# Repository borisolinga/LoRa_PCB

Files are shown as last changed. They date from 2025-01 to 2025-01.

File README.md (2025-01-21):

# LoRa-Sender PCB

Die Leiterplatte (PCB) des LoRa-Senders deckt alle für dieses Projekt erforderlichen Funktionen ab. Das Design des Schaltplans und der Platinenlayouts wurde mit der EDA-Software (Electronic Design Automation) **Autodesk EAGLE** entwickelt.

## Eigenschaften der Leiterplatte

Die Leiterplatte bietet folgende Hauptfunktionen:

- **LoRa-Datenübertragung:** Das Board ermöglicht eine zuverlässige Kommunikation über LoRa.
- **Status-LED:** Eine LED zeigt durch Blinken an, wenn ein Paket erfolgreich gesendet wurde.
- **Serielle Schnittstelle:** Eine UART/USB-Schnittstelle ermöglicht die Kommunikation mit einem Computer.
- **Mikrocontroller:**  
  - **ATmega328P**, der aufgrund seiner Kompatibilität mit Arduino-Entwicklungsboards ausgewählt wurde.  
 
- **Stromverbrauchsmessung:**  
  - Zwei Jumper sind zur Stromverbrauchsanalyse vorgesehen:  
    1. Für das LoRa-Modul.  
    2. Für das Gesamtsystem.
  - Ein zusätzlicher Jumper ermöglicht die Nutzung einer externen Stromversorgung.

## Projektinhalt

- **Schaltplan:** Enthält das vollständige PCB-Design in Autodesk EAGLE.
- **Stückliste (BOM):** Eine vollständige Liste der verwendeten Komponenten.

## Nutzung

1. **Repository klonen:**

   ```bash
   git clone https://github.com/borisolinga/LoRa_Transmitter_PCB.git
   cd LoRa_Transmitter_PCB

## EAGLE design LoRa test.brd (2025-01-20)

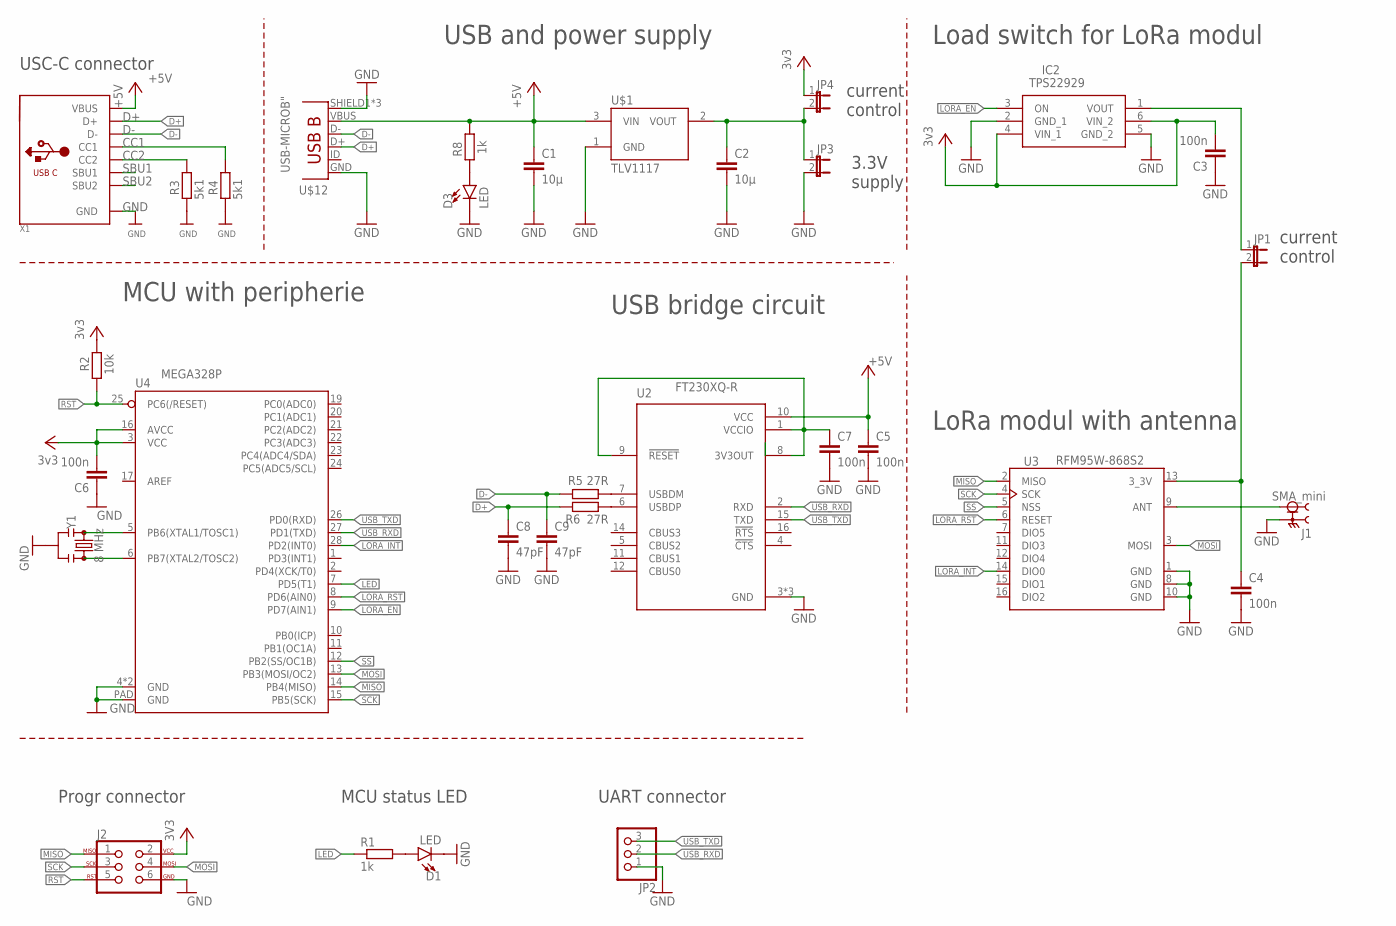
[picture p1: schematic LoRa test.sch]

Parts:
C1, C2: 10µ; C1206K
C3, C4, C5, C6, C7: 100n; C0603
C8, C9: 47pF; C0603
D1, D3: LED; LED-0603
IC2: TPS22929; SOP95P280X145-6N
J1: SMA_mini; LPRS_SMA_CONNECTOR
J2: AVR_SPI_PROG_3X2NS; 2X3-NS
JP1, JP3, JP4: JP1E; JP1
JP2: PINHD-1X3; 1X03
R1, R8: 1k; R0603
R2: 10k; R0603
R3, R4: 5k1; R0603
R5, R6: 27R; R0603
U2: FT230XQ-R; QFN65P400X400X80-17N
U3: RFM95W-868S2; XCVR_RFM95W-868S2
U4: MEGA328P; VQFN-28
U$1: TLV1117; SOT223
U$12: USB-MICROB"; USB-B-MICRO-SMD_V03
X1: USB_C; USB_C_CUSB31-CFM2AX-01-X
Y1: 8 MHz; RESONATOR-SMD-3.2X1.3

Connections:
+5V: C1.1, C5.1, R8.1, U2.10 (VCC), U$1.3 (VIN), U$12.VBUS, X1.A4B9 (VBUS), X1.B4A9 (VBUS)
CC1: R4.1, X1.A5 (CC1)
CC2: R3.1, X1.B5 (CC2)
D+: C8.1, R6.2, U$12.D+, X1.A6 (D+), X1.B6 (D+)
D-: C9.1, R5.2, U$12.D-, X1.A7 (D-), X1.B7 (D-)
GND: C1.2, C2.2, C3.1, C4.2, C5.2, C6.1, C7.2, C8.2, C9.2, D1.C, D3.C, IC2.2 (GND_1), IC2.5 (GND_2), J1.G1 (2), J1.G2 (2), J1.G3 (2), J1.G4 (2), J2.6, JP2.1, JP3.2, R3.2, R4.2, U2.3 (GND), U2.13 (GND), U2.17 (GND), U3.1 (GND), U3.8 (GND), U3.10 (GND), U4.4 (GND), U4.18 (GND), U4.PAD (GND), U$1.1 (GND), U$12.GND, U$12.SHIELD1 (SHIELD), U$12.SHIELD2 (SHIELD), U$12.SHIELD3 (SHIELD), X1.A1B12 (GND), X1.B1A12 (GND), Y1.2
LED: R1.1, U4.7 (PD5(T1))
LORA_EN: IC2.3 (ON), U4.9 (PD7(AIN1))
LORA_INT: U3.14 (DIO0), U4.28 (PD2(INT0))
LORA_RST: U3.6 (RESET), U4.8 (PD6(AIN0))
MISO: J2.1, U3.2 (MISO), U4.14 (PB4(MISO))
MOSI: J2.4, U3.3 (MOSI), U4.13 (PB3(MOSI/OC2))
unnamed: D1.A, R1.2
unnamed: J1.1, U3.9 (ANT)
unnamed: R5.1, U2.7 (USBDM)
unnamed: IC2.1 (VOUT), JP1.1
unnamed: D3.A, R8.2
unnamed: R6.1, U2.6 (USBDP)
unnamed: C7.1, U2.1 (VCCIO), U2.8 (3V3OUT), U2.9 (!RESET!)
unnamed: U4.5 (PB6(XTAL1/TOSC1)), Y1.1
unnamed: U4.6 (PB7(XTAL2/TOSC2)), Y1.3
unnamed: C2.1, JP3.1, JP4.2, U$1.2 (VOUT), U$1.4 (VOUT2)
unnamed: C4.1, JP1.2, U3.13 (3_3V)
RST: J2.5, R2.2, U4.25 (PC6(/RESET))
SBU1: X1.A8 (SBU1)
SBU2: X1.B8 (SBU2)
SCK: J2.3, U3.4 (SCK), U4.15 (PB5(SCK))
SS: U3.5 (NSS), U4.12 (PB2(SS/OC1B))
USB_RXD: JP2.2, U2.2 (RXD), U4.27 (PD1(TXD))
USB_TXD: JP2.3, U2.15 (TXD), U4.26 (PD0(RXD))
VCC: C3.2, C6.2, IC2.4 (VIN_1), IC2.6 (VIN_2), J2.2, JP4.1, R2.1, U4.3 (VCC), U4.16 (AVCC)

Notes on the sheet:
USB and power supply
Load switch for LoRa modul
USB bridge circuit
LoRa modul with antenna
current control
3.3V supply
MCU with peripherie
MCU status LED
Progr connector
USC-C connector
UART connector

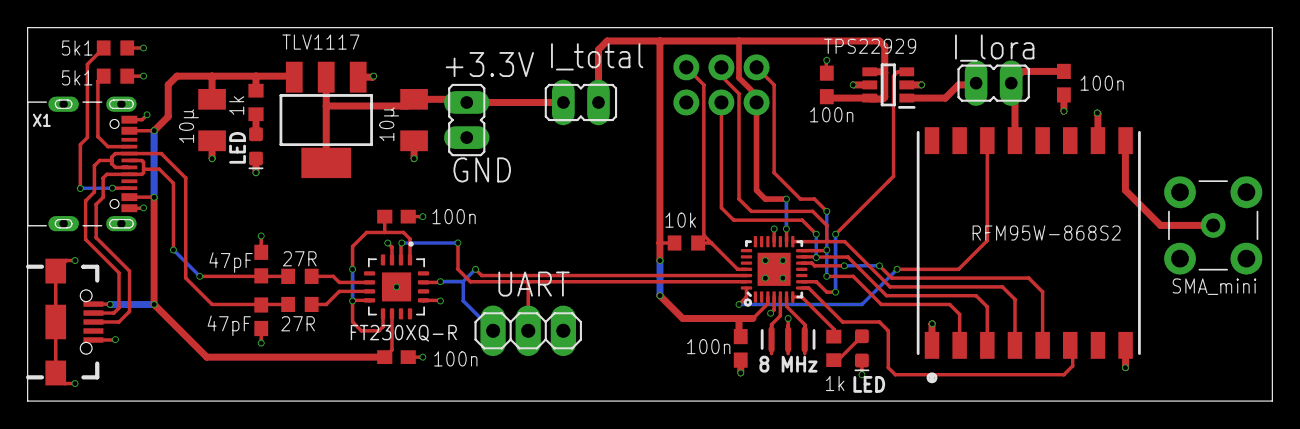
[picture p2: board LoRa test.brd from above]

Board: 2 copper layers, 90.0 x 27.0 mm, 32 parts (0 on the bottom side), 29 nets.

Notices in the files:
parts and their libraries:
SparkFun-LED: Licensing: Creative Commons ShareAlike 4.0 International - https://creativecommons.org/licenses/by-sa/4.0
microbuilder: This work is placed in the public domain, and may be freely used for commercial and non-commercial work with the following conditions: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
